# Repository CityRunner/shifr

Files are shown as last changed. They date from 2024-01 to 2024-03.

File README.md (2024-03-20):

# Shifr Keyboard

Shifr (ШИФР) is a compact wireless mechanical keyboard featuring only 40 switches.

The exclusive use of through-hole components simplifies assembly and contributes to its rugged DIY aesthetic.

# Images
| Front | Back |
|---|---|
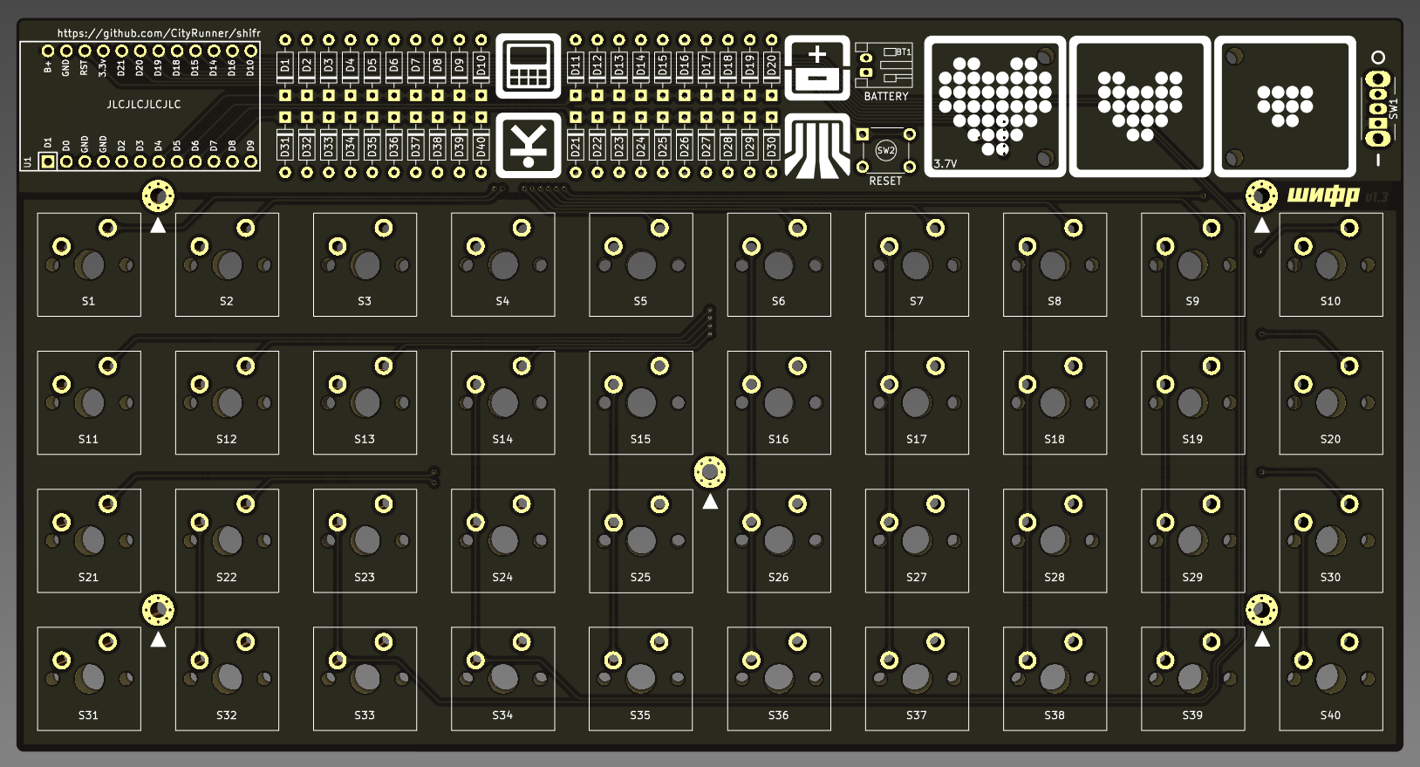
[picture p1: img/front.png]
front
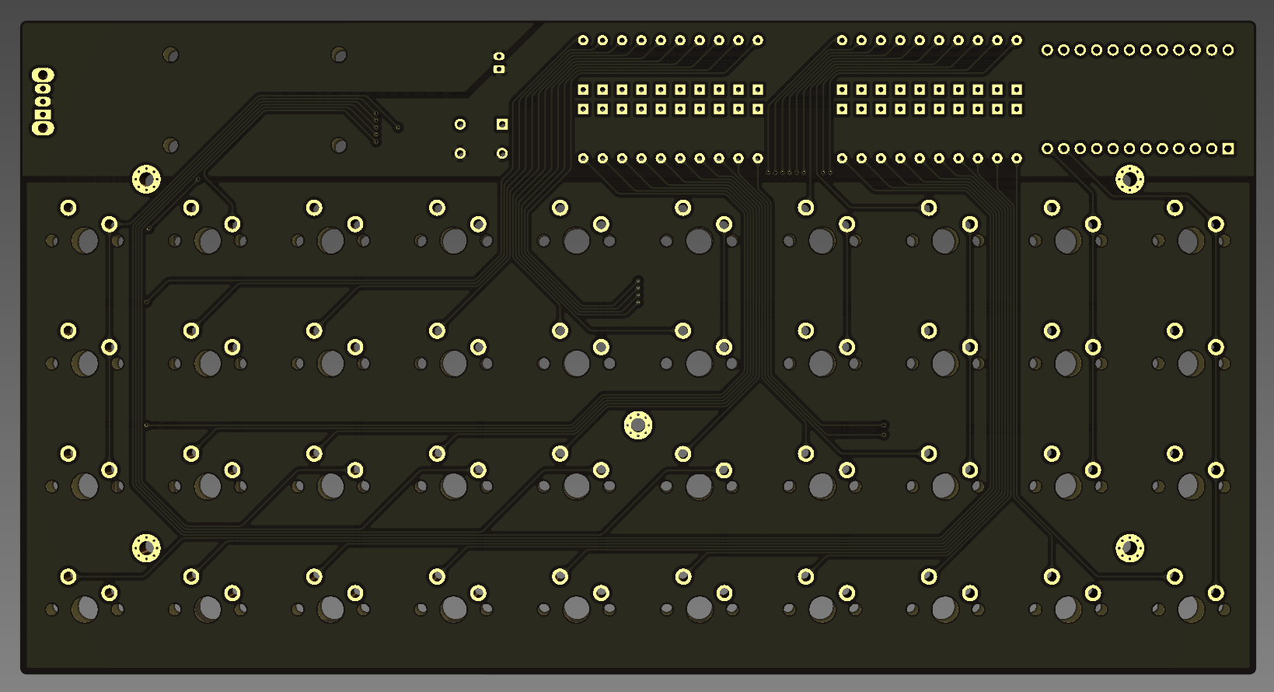
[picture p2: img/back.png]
back
|  |  |

# Layout
Default layout is Colemak-DH with homerow mods.
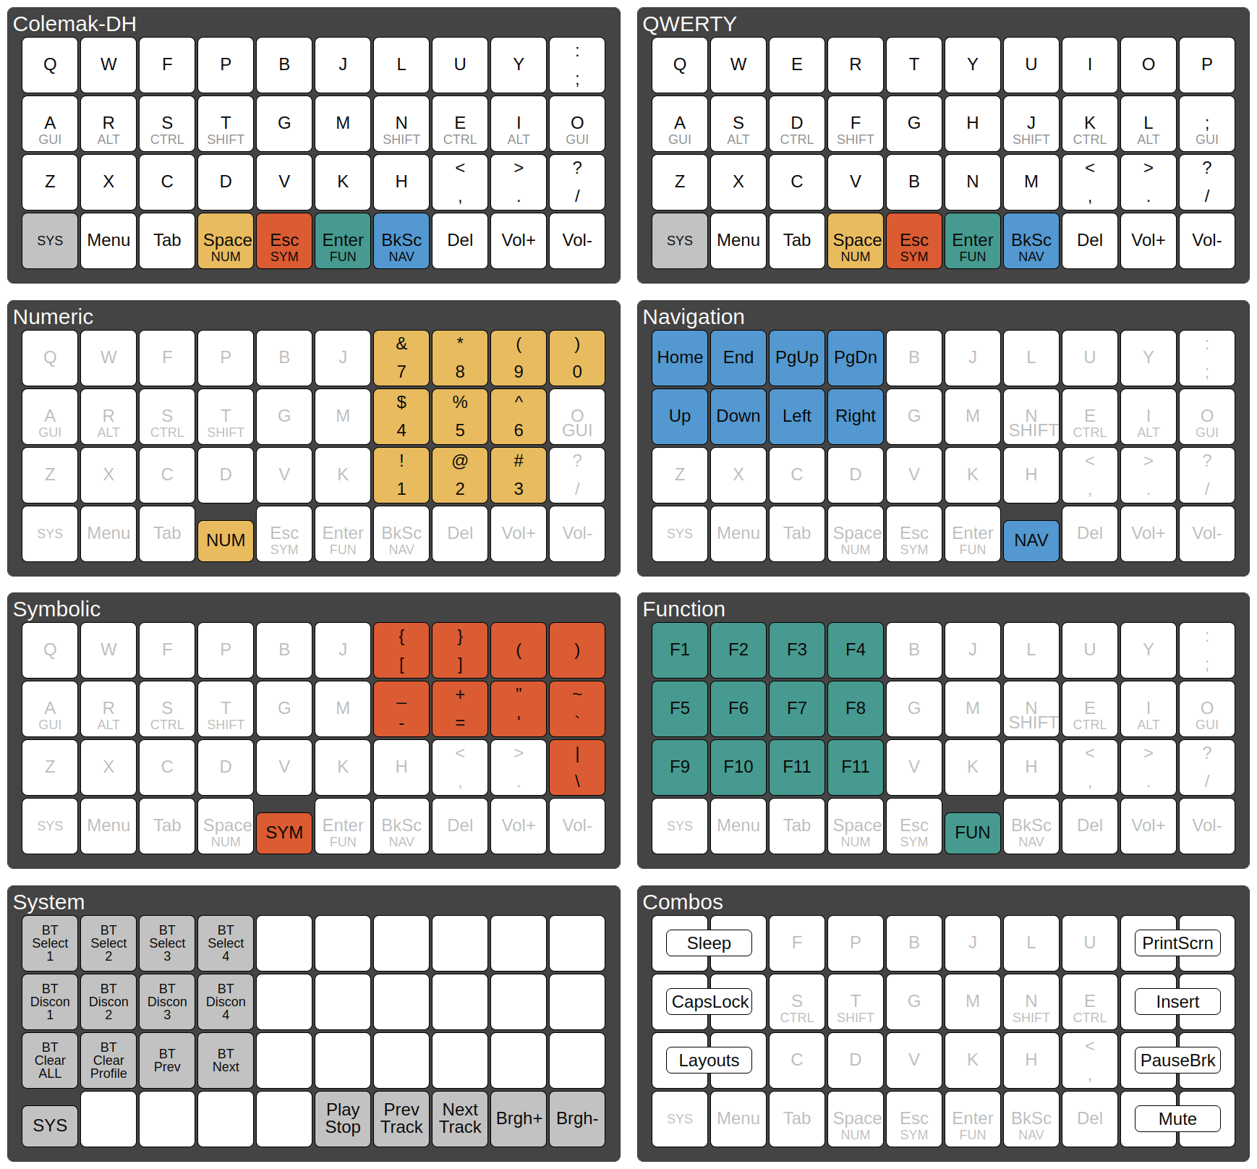
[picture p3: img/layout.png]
layout


# Building

## Bill of materials
| Value | Designator | Footprint | Quantity |
|---|---|---|---|
| Battery | BT1 | JST_PH_S2B-PH-K_1x02_P2.00mm_Horizontal | 1 |
| Diode | D1 - D40 | Diode_DO-35 | 40 |
| Keyswitch | S1 - S40 | MX_PCB_1.00u | 40 |
| Power Switch | SW1 | SW_CuK_OS102011MA1QN1_SPDT_Angled | 1 |
| Reset Switch | SW2 | SW_TH_Tactile_Omron_B3F-10xx | 1 |
| Nice_Nano_V2 | U1 | Nice_Nano_V2 | 1 |
| Cherry MX Keycaps | - | - | 40 |
| 3.7V LiPo Battery | - | - | 1 |
| M2 Screws with Nuts | - | - | 5 |
| 3mm Spacers | - | - | 5 |

## Firmware
1. Download and unpack [misc/](https://github.com/CityRunner/shifr/tree/main/misc)firmware.zip.
2. Double-tap the Reset button on the keyboard.
3. Copy "shifr-nice_nano_v2-zmk.uf2" onto the root directory of the USB storage that appears.
4. The controller should flash the firmware and automatically restart once flashing is complete.

Source code available here: [Shifr ZMK](https://github.com/CityRunner/shifr-zmk)

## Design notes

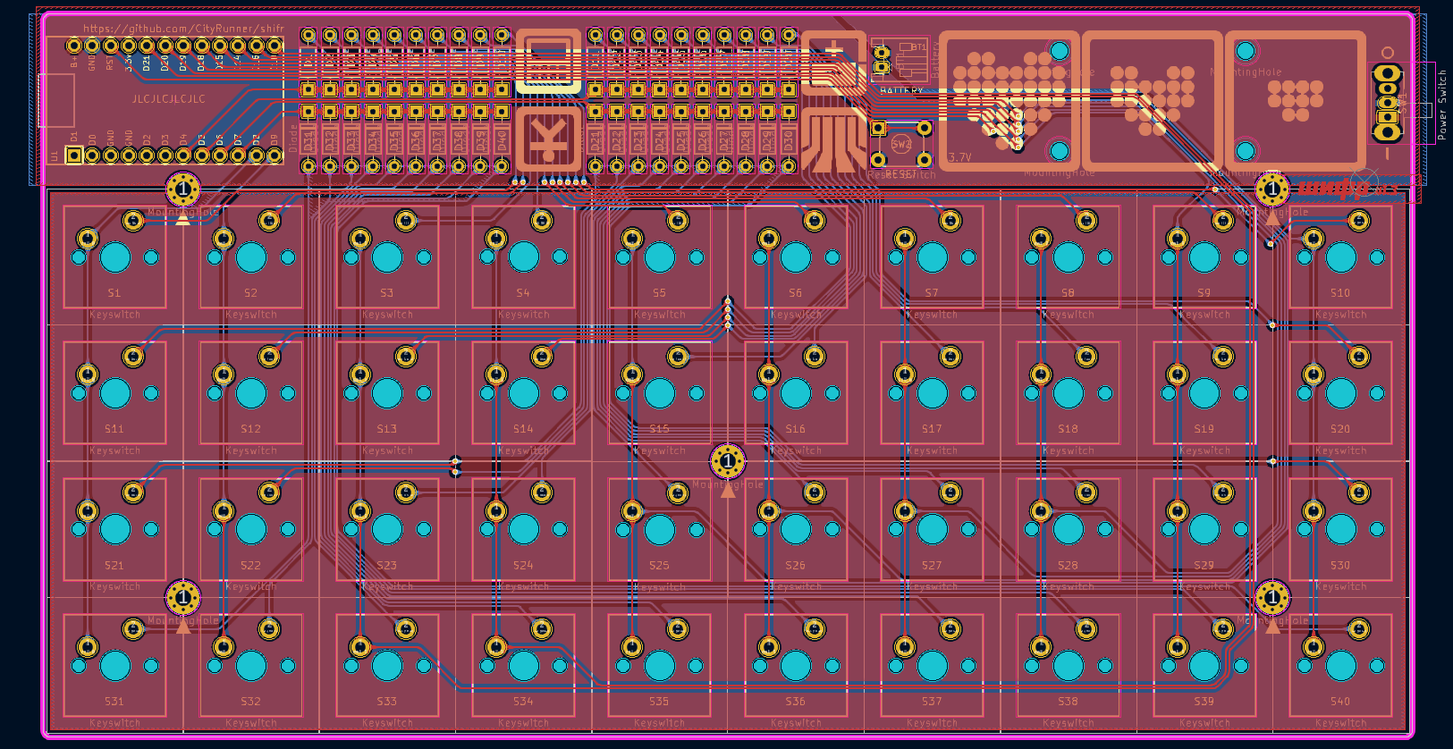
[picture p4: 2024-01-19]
img/pcb.png

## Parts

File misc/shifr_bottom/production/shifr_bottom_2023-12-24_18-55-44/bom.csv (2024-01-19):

Designator | Footprint | Quantity | Value | LCSC Part #
H1, H2, H3, H4, H5 | MountingHole_2.2mm_M2_Pad_Via | 5 | MountingHole

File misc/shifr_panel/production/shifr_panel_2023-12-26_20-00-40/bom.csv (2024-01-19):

Designator | Footprint | Quantity | Value | LCSC Part #
H1, H2, H3, H4, H5 | MountingHole_2.2mm_M2_Pad_Via | 5 | MountingHole
S1, S10, S11, S12, S13, S14, S15, S16, S17, S18, S19, S2, S20, S21, S22, S23, S24, S25, S26, S27, S28, S29, S3, S30, S31, S32, S33, S34, S35, S36, S37, S38, S39, S4, S40, S5, S6, S7, S8, S9 | Cutout_MX_1.00u | 40 | Keyswitch

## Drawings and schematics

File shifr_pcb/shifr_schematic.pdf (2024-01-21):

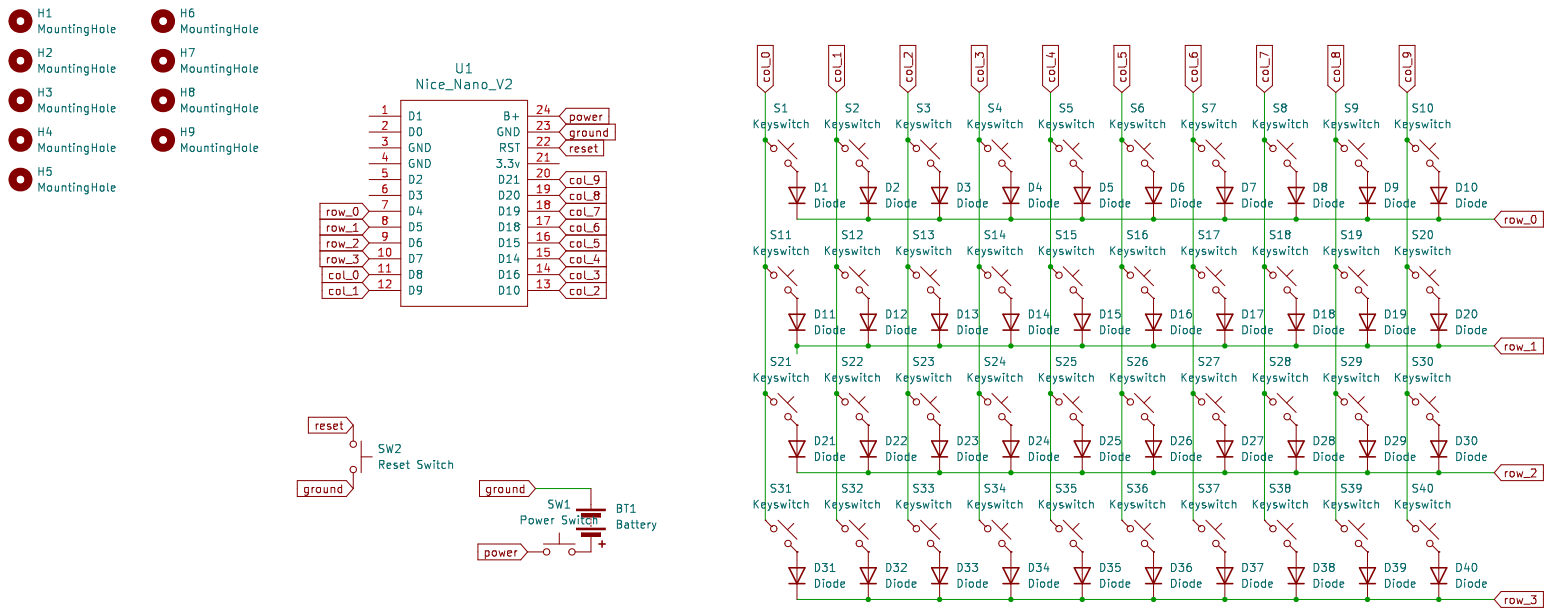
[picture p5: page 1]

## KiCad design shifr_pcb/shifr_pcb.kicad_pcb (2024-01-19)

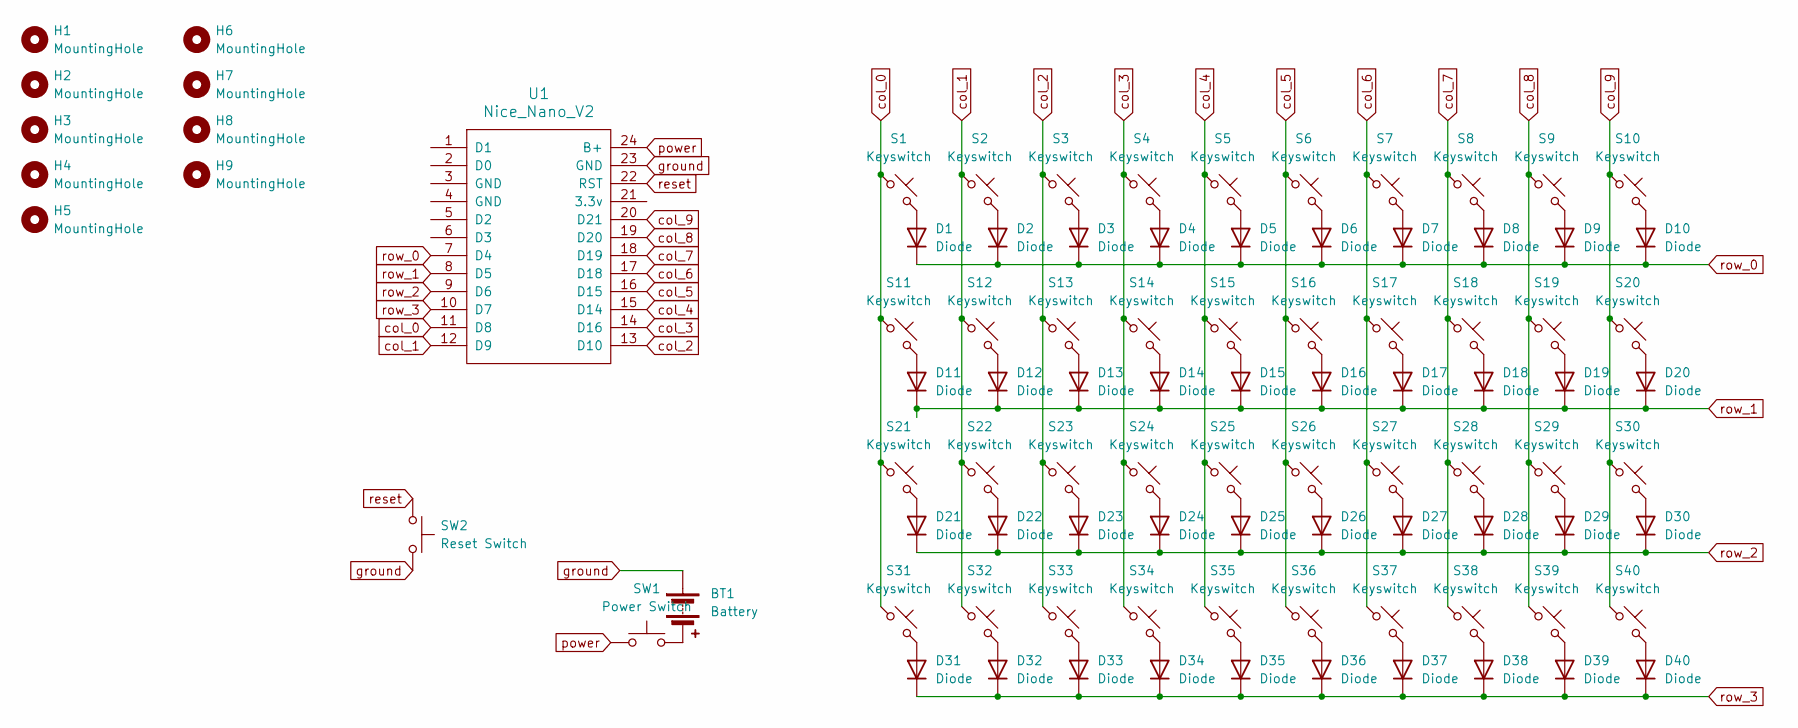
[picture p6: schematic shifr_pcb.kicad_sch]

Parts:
BT1: Battery; JST_PH_S2B-PH-K_1x02_P2.00mm_Horizontal
D1, D2, D3, D4, D5, D6, D7, D8, D9, D10, D11, D12, D13, D14, D15, D16, D17, D18, D19, D20, D21, D22, D23, D24, D25, D26, D27, D28, D29, D30, D31, D32, D33, D34, D35, D36, D37, D38, D39, D40: Diode; Diode_DO-35
H1, H2, H3, H4, H5: MountingHole; MountingHole_2.2mm_M2_Pad_Via
H6, H7, H8, H9: MountingHole; MountingHole_2.2mm_M2_ISO14580
S1, S2, S3, S4, S5, S6, S7, S8, S9, S10, S11, S12, S13, S14, S15, S16, S17, S18, S19, S20, S21, S22, S23, S24, S25, S26, S27, S28, S29, S30, S31, S32, S33, S34, S35, S36, S37, S38, S39, S40: Keyswitch; MX_PCB_1.00u
SW1: Power Switch; SW_CuK_OS102011MA1QN1_SPDT_Angled
SW2: Reset Switch; SW_TH_Tactile_Omron_B3F-10xx
U1: Nice_Nano_V2

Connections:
unnamed: BT1.2 (-), SW1.2
unnamed: D1.2 (A), S1.2
unnamed: D2.2 (A), S2.2
unnamed: D3.2 (A), S3.2
unnamed: D4.2 (A), S4.2
unnamed: D5.2 (A), S5.2
unnamed: D6.2 (A), S6.2
unnamed: D7.2 (A), S7.2
unnamed: D8.2 (A), S8.2
unnamed: D9.2 (A), S9.2
unnamed: D10.2 (A), S10.2
unnamed: D11.2 (A), S11.2
unnamed: D12.2 (A), S12.2
unnamed: D13.2 (A), S13.2
unnamed: D14.2 (A), S14.2
unnamed: D15.2 (A), S15.2
unnamed: D16.2 (A), S16.2
unnamed: D17.2 (A), S17.2
unnamed: D18.2 (A), S18.2
unnamed: D19.2 (A), S19.2
unnamed: D20.2 (A), S20.2
unnamed: D21.2 (A), S21.2
unnamed: D22.2 (A), S22.2
unnamed: D23.2 (A), S23.2
unnamed: D24.2 (A), S24.2
unnamed: D25.2 (A), S25.2
unnamed: D26.2 (A), S26.2
unnamed: D27.2 (A), S27.2
unnamed: D28.2 (A), S28.2
unnamed: D29.2 (A), S29.2
unnamed: D30.2 (A), S30.2
unnamed: D31.2 (A), S31.2
unnamed: D32.2 (A), S32.2
unnamed: D33.2 (A), S33.2
unnamed: D34.2 (A), S34.2
unnamed: D35.2 (A), S35.2
unnamed: D36.2 (A), S36.2
unnamed: D37.2 (A), S37.2
unnamed: D38.2 (A), S38.2
unnamed: D39.2 (A), S39.2
unnamed: D40.2 (A), S40.2
col_0: S1.1, S11.1, S21.1, S31.1, U1.11 (D8)
col_1: S2.1, S12.1, S22.1, S32.1, U1.12 (D9)
col_2: S3.1, S13.1, S23.1, S33.1, U1.13 (D10)
col_3: S4.1, S14.1, S24.1, S34.1, U1.14 (D16)
col_4: S5.1, S15.1, S25.1, S35.1, U1.15 (D14)
col_5: S6.1, S16.1, S26.1, S36.1, U1.16 (D15)
col_6: S7.1, S17.1, S27.1, S37.1, U1.17 (D18)
col_7: S8.1, S18.1, S28.1, S38.1, U1.18 (D19)
col_8: S9.1, S19.1, S29.1, S39.1, U1.19 (D20)
col_9: S10.1, S20.1, S30.1, S40.1, U1.20 (D21)
ground: BT1.1 (+), SW2.2, U1.23 (GND)
power: SW1.1, U1.24 (B+)
reset: SW2.1, U1.22 (RST)
row_0: D1.1 (K), D2.1 (K), D3.1 (K), D4.1 (K), D5.1 (K), D6.1 (K), D7.1 (K), D8.1 (K), D9.1 (K), D10.1 (K), U1.7 (D4)
row_1: D11.1 (K), D12.1 (K), D13.1 (K), D14.1 (K), D15.1 (K), D16.1 (K), D17.1 (K), D18.1 (K), D19.1 (K), D20.1 (K), U1.8 (D5)
row_2: D21.1 (K), D22.1 (K), D23.1 (K), D24.1 (K), D25.1 (K), D26.1 (K), D27.1 (K), D28.1 (K), D29.1 (K), D30.1 (K), U1.9 (D6)
row_3: D31.1 (K), D32.1 (K), D33.1 (K), D34.1 (K), D35.1 (K), D36.1 (K), D37.1 (K), D38.1 (K), D39.1 (K), D40.1 (K), U1.10 (D7)

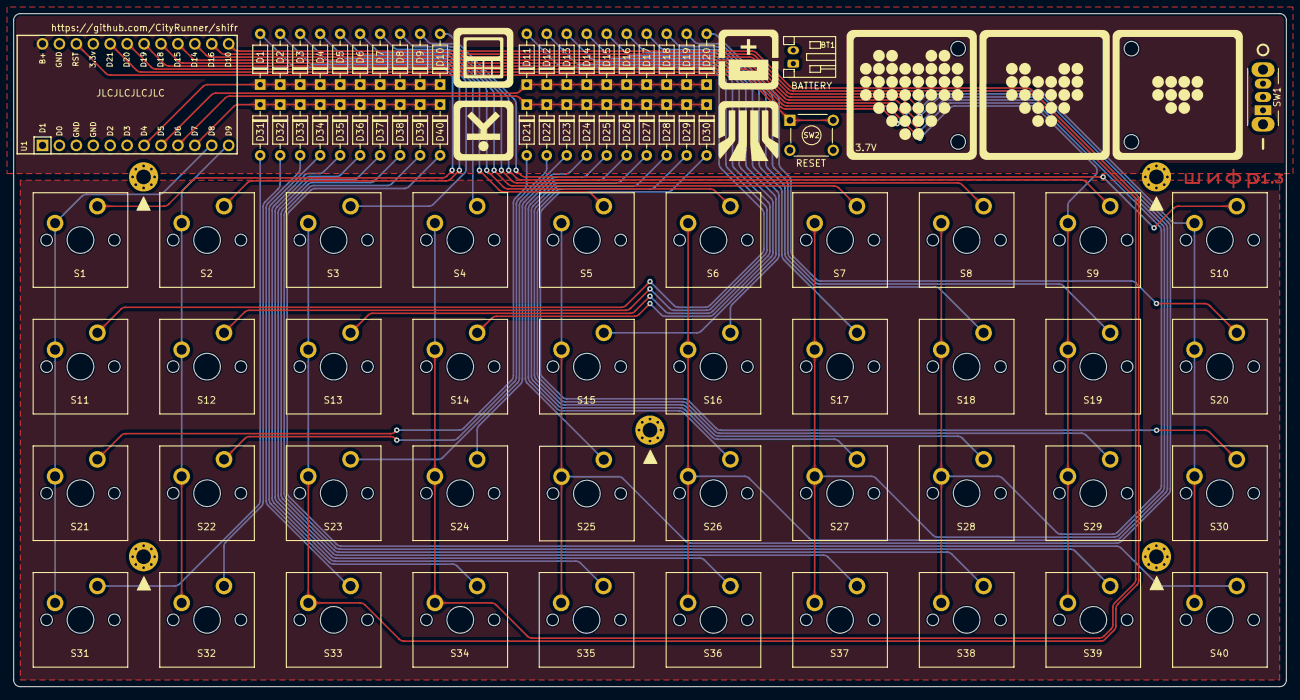
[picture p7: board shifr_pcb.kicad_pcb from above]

Board: 2 copper layers, 191.0 x 101.0 mm, 93 parts (0 on the bottom side), 58 nets.

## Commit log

2024-01-19 Upload project files
    [bom.csv, designators.csv, positions.csv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]
2024-01-21 Replace schematic image with pdf
2024-01-21 Remove production files
    [bom.csv, designators.csv, positions.csv]
